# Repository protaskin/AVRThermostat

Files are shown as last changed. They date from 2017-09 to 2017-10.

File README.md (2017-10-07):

# AVRThermostat

AVRThermostat is, as the name implies, a programmable thermostat, which is built
on

* Atmel AVR ATmega8A microcontroller,

* digital thermometer DS18B20 by Maxim Integrated,

* four-digit seven-segment led display with common cathode (like CC56-12 or
FYQ-5641A),

and uses a relay to control a heater or fan. The device can be used as a simple
thermometer as well. The sensor measures temperatures from -55°C to +125°C
with ±0.5°C accuracy from -10°C to +85°C.

The thermostat has 4 buttons (Plus, Minus, Set, Reset) that are used to set up
parameters--the setpoint and the zone (delta). The longer you hold the 
Plus/Minus button, the faster a parameter increases/decreases. The Reset button
is used to set the standard value to a parameter, also to switch off the
thermostat mode. Parameters are saved in EEPROM after editing.

The Plus/Minus buttons also are used to adjust the display brightness when
the device is not in the mode of editing of a parameter.

Two leds indicate the state of the relay. If the device is not in the thermostat
mode, then both leds do not light.

If the device cannot establish connection with the sensor, the display shows
an error.

## Schematics and PCB Layout r3.x

A KiCad project, which includes a schematics and PCB layout, is located in
[the Design directory](Design/). **Please be aware that the project is made from
scratch and I have not yet used the new PCB layout myself, therefore it may have
errors.**

### Schematics

Schematics r3.1

### PCB 3D Model

PCB 3D Model r3.0

## Versioning

For transparency and insight into our release cycle, and for striving to
maintain backwards compatibility, AVRThermostat will be maintained under the
Semantic Versioning guidelines as much as possible.

For more information on SemVer, please visit http://semver.org/

## License

Copyright 2014-2017 Artyom Protaskin

Licensed under the MIT License:

http://opensource.org/licenses/MIT

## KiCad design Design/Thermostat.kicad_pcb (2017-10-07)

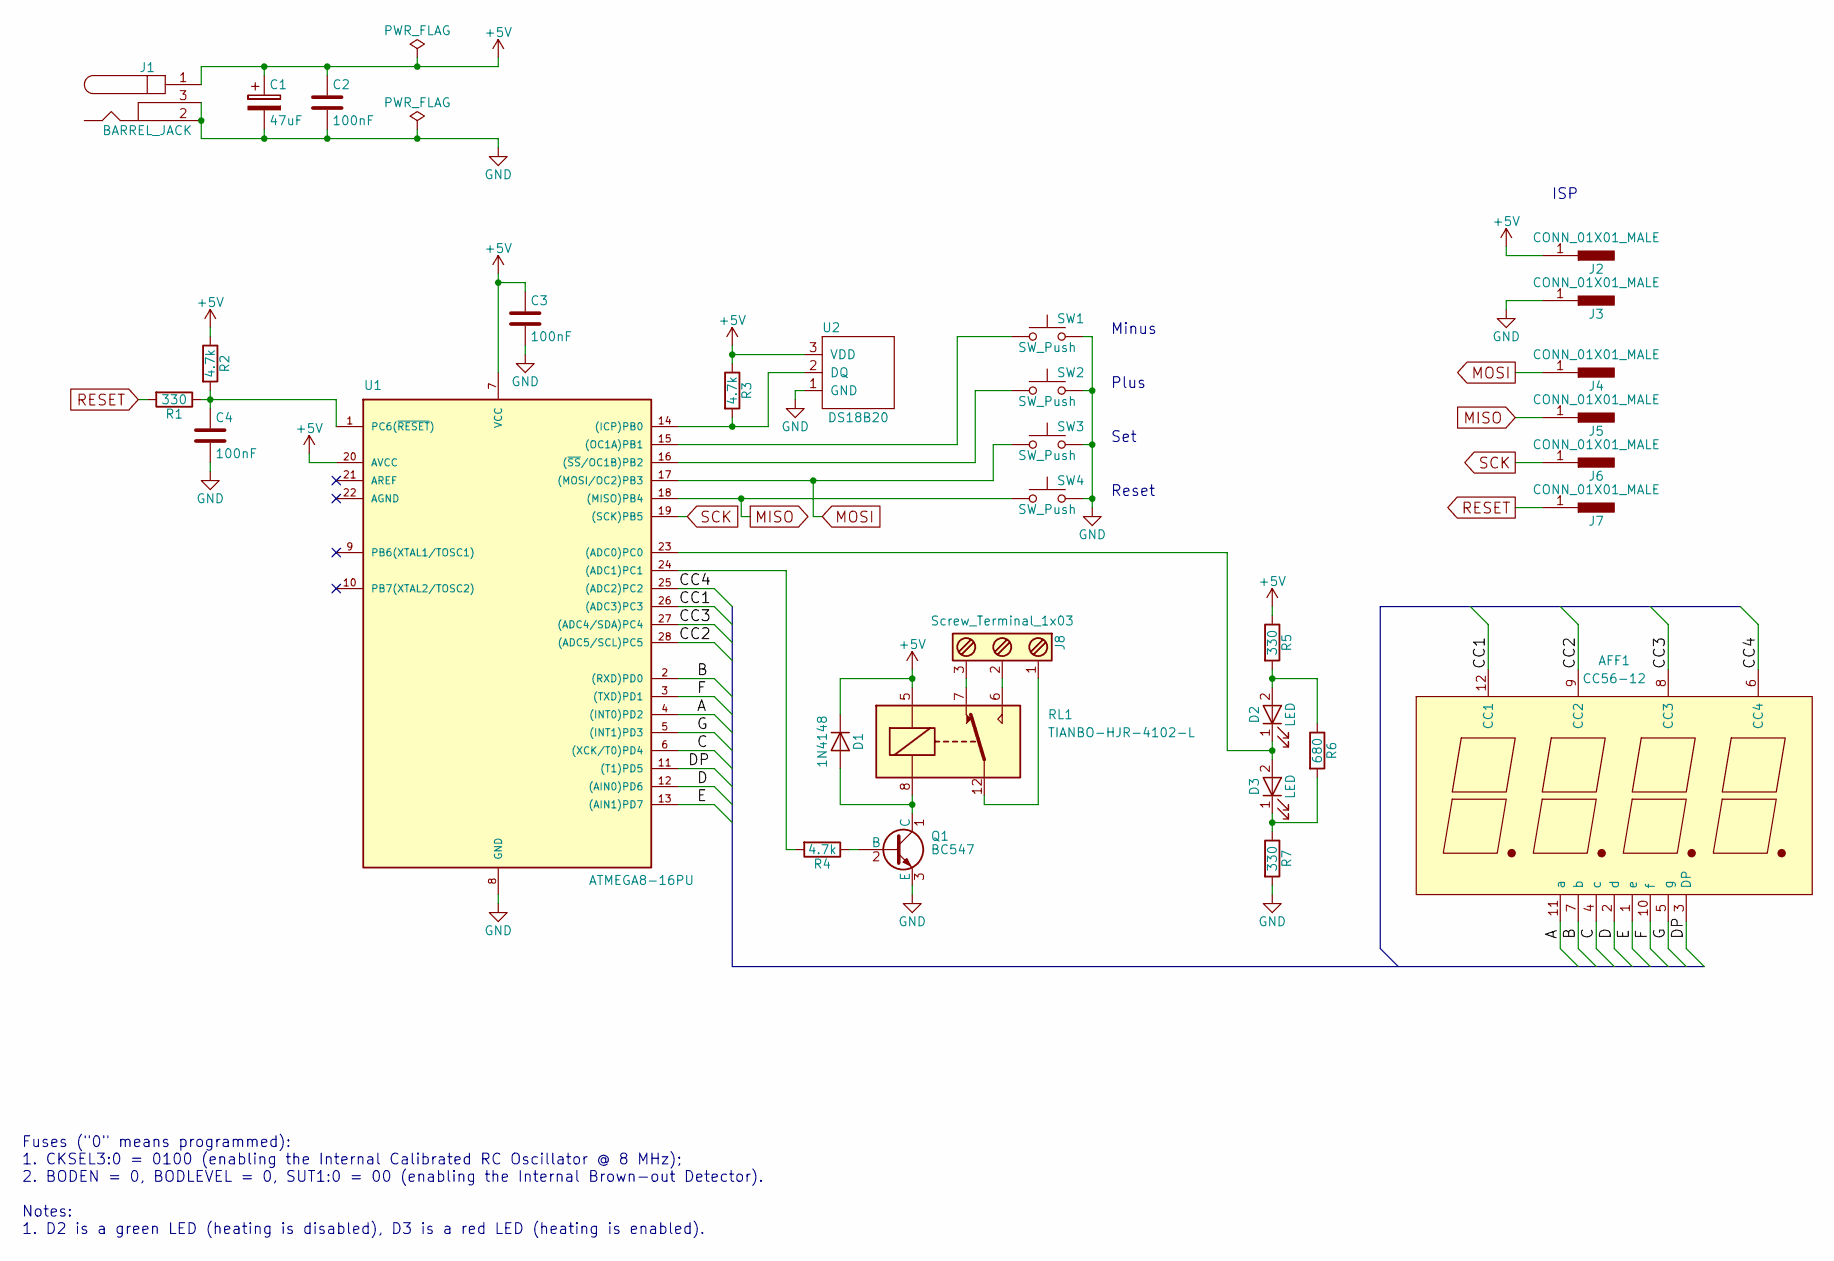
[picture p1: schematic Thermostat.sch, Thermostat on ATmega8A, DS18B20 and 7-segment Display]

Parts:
AFF1: CC56-12; CC56-12GWA
C1: 47uF; CP_Radial_D5.0mm_P2.00mm
C2, C3, C4: 100nF; C_Disc_D4.3mm_W1.9mm_P5.00mm
D1: 1N4148; D_DO-35_SOD27_P7.62mm_Horizontal
D2, D3: LED; LED_D3.0mm
J1: BARREL_JACK
J2, J3, J4, J5, J6, J7: CONN_01X01_MALE; Pin_Header_Straight_1x01_Pitch2.54mm
J8: Screw_Terminal_1x03; TerminalBlock_Pheonix_MKDS1.5-3pol
Q1: BC547; TO-92_Molded_Narrow
R1, R5, R7: 330; R_Axial_DIN0207_L6.3mm_D2.5mm_P10.16mm_Horizontal
R2, R3, R4: 4.7k; R_Axial_DIN0207_L6.3mm_D2.5mm_P10.16mm_Horizontal
R6: 680; R_Axial_DIN0207_L6.3mm_D2.5mm_P10.16mm_Horizontal
RL1: TIANBO-HJR-4102-L; Relay_SPDT_HJR-4102
SW1, SW2, SW3, SW4: SW_Push; SW_PUSH_6mm_h5mm
U1: ATMEGA8-16PU; DIP-28_W7.62mm
U2: DS18B20; TO-92_Molded_Narrow

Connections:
+5V: C1.1, C2.1, C3.1, D1.1 (K), J1.1, J2.1, R2.1, R3.1, R5.1, RL1.5, U1.7 (VCC), U1.20 (AVCC), U2.3 (VDD)
/A: AFF1.11 (a), U1.4 ((INT0)PD2)
/B: AFF1.7 (b), U1.2 ((RXD)PD0)
/C: AFF1.4 (c), U1.6 ((XCK/T0)PD4)
/CC1: AFF1.12 (CC1), U1.26 ((ADC3)PC3)
/CC2: AFF1.9 (CC2), U1.28 ((ADC5/SCL)PC5)
/CC3: AFF1.8 (CC3), U1.27 ((ADC4/SDA)PC4)
/CC4: AFF1.6 (CC4), U1.25 ((ADC2)PC2)
/D: AFF1.2 (d), U1.12 ((AIN0)PD6)
/DP: AFF1.3 (DP), U1.11 ((T1)PD5)
/E: AFF1.1 (e), U1.13 ((AIN1)PD7)
/F: AFF1.10 (f), U1.3 ((TXD)PD1)
/G: AFF1.5 (g), U1.5 ((INT1)PD3)
GND: C1.2, C2.2, C3.2, C4.2, J1.2, J1.3, J3.1, Q1.3 (E), R7.2, SW1.2, SW2.2, SW3.2, SW4.2, U1.8 (GND), U2.1 (GND)
MISO: J5.1, SW4.1, U1.18 ((MISO)PB4)
MOSI: J4.1, SW3.1, U1.17 ((MOSI/OC2)PB3)
unnamed: C4.1, R1.1, R2.2, U1.1 (PC6(~RESET~))
unnamed: D1.2 (A), Q1.1 (C), RL1.8
unnamed: D2.1 (K), D3.2 (A), U1.23 ((ADC0)PC0)
unnamed: D2.2 (A), R5.2, R6.1
unnamed: D3.1 (K), R6.2, R7.1
unnamed: J8.1, RL1.12
unnamed: J8.2, RL1.6
unnamed: J8.3, RL1.7
unnamed: Q1.2 (B), R4.1
unnamed: R3.2, U1.14 ((ICP)PB0), U2.2 (DQ)
unnamed: R4.2, U1.24 ((ADC1)PC1)
unnamed: SW1.1, U1.15 ((OC1A)PB1)
unnamed: SW2.1, U1.16 ((~SS~/OC1B)PB2)
RESET: J7.1, R1.2
SCK: J6.1, U1.19 ((SCK)PB5)

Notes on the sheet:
Minus
Plus
Set
Reset
ISP
Fuses ("0" means programmed): 1. CKSEL3:0 = 0100 (enabling the Internal Calibrated RC Oscillator @ 8 MHz); 2. BODEN = 0, BODLEVEL = 0, SUT1:0 = 00 (enabling the Internal Brown-out Detector). Notes: 1. D2 is a green LED (heating is disabled), D3 is a red LED (heating is enabled).

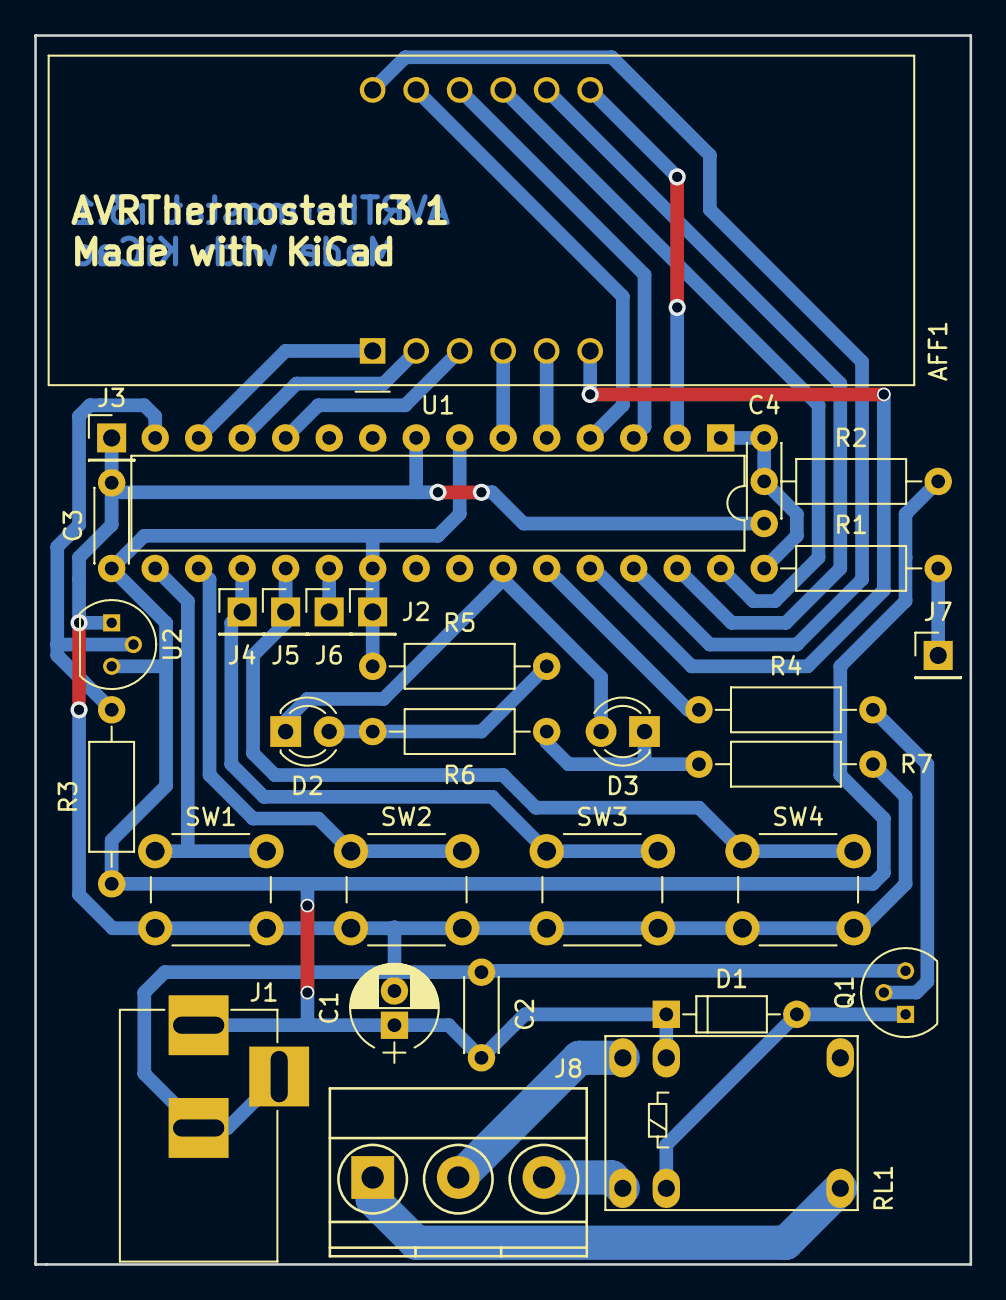
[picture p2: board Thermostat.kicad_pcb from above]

Board: 2 copper layers, 54.6 x 71.8 mm, 31 parts (0 on the bottom side), 31 nets.

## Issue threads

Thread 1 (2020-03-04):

7segment

sewer159, 2020-03-04:
Hi.
Is it possible to easily change display with a common cathode on one with common anode?

protaskin, 2020-03-05:
Not without editing/rewriting the display "driver". And hardware-wise it would probably require using transistors to switch higher output anode currents.

https://github.com/protaskin/AVRThermostat/blob/master/Thermostat/display.c
https://github.com/protaskin/AVRThermostat/blob/master/Thermostat/display.h

Closed 2020-03-06.

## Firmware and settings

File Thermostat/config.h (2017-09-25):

/*
 * This file is part of AVRThermostat.
 *
 * (c) Artyom Protaskin <a.protaskin@gmail.com>
 *
 * For the full copyright and license information, please view the LICENSE
 * file that was distributed with this source code.
 */

#ifndef CONFIG_H
#define CONFIG_H

// Limits
#define ZERO_TEMP 0
#define MIN_TEMP 0xFC90 // -55
#define MAX_TEMP 0x07D0 // 125
#define MIN_ZONE 0x0001 // 1/16
#define MAX_ZONE 0x0640 // 100
#define MIN_BRIGHTNESS 1
#define MAX_BRIGHTNESS 15

// Default values
#define DEFAULT_TASK 0x0140 // 20
#define DEFAULT_ZONE 0x0008 // 0.5
#define DEFAULT_BRIGHTNESS 7 // 1/2
#define DEFAULT_ACTION 0
#define DEFAULT_CHECKSUM 0x95

// Error bit offsets
#define CONFIG_BAD_TASK_BIT 0
#define CONFIG_BAD_ZONE_BIT 1
#define CONFIG_BAD_BRIGHTNESS_BIT 2
#define CONFIG_BAD_ACTION_BIT 3
#define CONFIG_BAD_CHECKSUM_BIT 4

#include <stdint.h>

extern uint16_t task;
extern uint16_t zone;
extern uint8_t brightness;
extern uint8_t action;

uint8_t config_read(void);

uint8_t config_update(void);

#endif /* CONFIG_H */

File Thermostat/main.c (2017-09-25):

/*
 * This file is part of AVRThermostat.
 *
 * (c) Artyom Protaskin <a.protaskin@gmail.com>
 *
 * For the full copyright and license information, please view the LICENSE
 * file that was distributed with this source code.
 */

#define TIMER1_SHOW_TEMP_BIT    0
#define TIMER1_CONTROL_TEMP_BIT 1

#include <stdbool.h>
#include <stdint.h>
#include <util/delay.h>
#include <avr/interrupt.h>
#include <avr/io.h>

#include "buttons.h"
#include "display.h"
#include "config.h"
#include "ds18b20.h"
#include "iodef.h"

static uint8_t timer1_status;
static volatile uint16_t temp = 0xDEAD;

static const uint8_t * const numbers = display_numbers_map;

/**
 * Разбивает значение, считанное из температурного регистра на рязряды и
 * заполняет регистр дисплея.
 */
static void fill_display_register(uint16_t temp)
{
	bool sign;
	uint8_t int_part, frac_numer;

	if (temp == DS18B20_ERROR) {
		display_register[3] = DISPLAY_CHAR_BLANK;
		display_register[2] = DISPLAY_CHAR_E;
		display_register[1] = DISPLAY_CHAR_R;
		display_register[0] = DISPLAY_CHAR_R;
		return;
	}

	// Определение знака
	sign = ((temp & 0xF800) == 0xF800);
	if (sign) {
		// Преобразование из дополнительного представления числа в прямое
		temp = ~temp + 1;
	}

	// Выделение целой части
	int_part = (temp & 0x07F0) >> 4;

	// Выделение дробной части
	frac_numer = (temp & 0x0F) * 625 / 100;
	frac_numer = frac_numer / 10 + (frac_numer % 10 >= 5);

	// Заполнение регистра дисплея
	if (int_part >= 100) {
		display_register[3] = numbers[1];
	} else if (sign && int_part >= 10) {
		display_register[3] = DISPLAY_CHAR_MINUS;
	} else {
		display_register[3] = DISPLAY_CHAR_BLANK;
	}

	if (int_part >= 10) {
		display_register[2] = numbers[int_part % 100 / 10];
	} else if (sign) {
		display_register[2] = DISPLAY_CHAR_MINUS;
	} else {
		display_register[2] = DISPLAY_CHAR_BLANK;
	}

	display_register[1] = numbers[int_part % 10] | DISPLAY_CHAR_POINT;
	display_register[0] = numbers[frac_numer];
}

/**
 * Считывает содержимое температурного регистра. Вызывается 1 раз в 2 с.
 */
ISR(TIMER1_COMPA_vect)
{
	uint16_t trigger_on;
	uint16_t trigger_off;

	temp = ds18b20_read_temp();

	if (timer1_status & _BV(TIMER1_SHOW_TEMP_BIT)) {
		fill_display_register(temp);
	}

	if (timer1_status & _BV(TIMER1_CONTROL_TEMP_BIT)) {
		trigger_on = task - zone / 2;
		trigger_off = task + zone / 2;

		// If temp >= MIN_TEMP is true, temp is negative,
		// If temp <= MAX_TEMP is true, temp is positive.
		if (temp >= MIN_TEMP) {
			if (trigger_on <= MAX_TEMP || temp <= trigger_on) {
				LED_PORT |= _BV(LED_BIT);
				RELAY_PORT |= _BV(RELAY_BIT);
			} else if (trigger_off >= MIN_TEMP && temp >= trigger_off) {
				LED_PORT &= ~_BV(LED_BIT);
				RELAY_PORT &= ~_BV(RELAY_BIT);
			}
		} else {
			if (trigger_on <= MAX_TEMP && temp <= trigger_on) {
				LED_PORT |= _BV(LED_BIT);
				RELAY_PORT |= _BV(RELAY_BIT);
			} else if (trigger_off >= MIN_TEMP || temp >= trigger_off) {
				LED_PORT &= ~_BV(LED_BIT);
				RELAY_PORT &= ~_BV(RELAY_BIT);
			}
		}
	}
}

/**
 * Отображает содержимое регистра дисплея. Вызывается 1 раз в 100 мкс.
 */
ISR(TIMER2_COMP_vect)
{
	static uint8_t i = 0;

	if (i == 0) {
		display_show();
	}

	if (i == brightness) {
		display_hide();
		display_next();
	}

	i++;
	i &= 0x0F; // 16 -> 0
}

static void show_temp()
{
	timer1_status |= _BV(TIMER1_SHOW_TEMP_BIT);
	fill_display_register(temp);

	for (;;) {
		if (button_is_pressed(&BUTTONS_PIN, MINUS_BUTTON_BIT)) {
			if (brightness > MIN_BRIGHTNESS) {
				brightness--;
				config_update();
			}
			while (!button_is_released(&BUTTONS_PIN, MINUS_BUTTON_BIT));
		} else if (button_is_pressed(&BUTTONS_PIN, PLUS_BUTTON_BIT)) {
			if (brightness < MAX_BRIGHTNESS) {
				brightness++;
				config_update();
			}
			while (!button_is_released(&BUTTONS_PIN, PLUS_BUTTON_BIT));
		} else if (button_is_pressed(&BUTTONS_PIN, SET_BUTTON_BIT)) {
			while (!button_is_released(&BUTTONS_PIN, SET_BUTTON_BIT));
			break;
		}
	}

	timer1_status &= ~_BV(TIMER1_SHOW_TEMP_BIT);
}

static void change_task()
{
	bool reset;

	fill_display_register(task);

	for (;;) {
		reset = true;
		if (button_is_pressed(&BUTTONS_PIN, MINUS_BUTTON_BIT)) {
			do {
				if (task <= MAX_TEMP || task > MIN_TEMP) {
					fill_display_register(--task);
				}
			} while (button_being_pressed(&BUTTONS_PIN, MINUS_BUTTON_BIT, &reset));
		} else if (button_is_pressed(&BUTTONS_PIN, PLUS_BUTTON_BIT)) {
			do {
				if (task < MAX_TEMP || task >= MIN_TEMP) {
					fill_display_register(++task);
				}
			} while (button_being_pressed(&BUTTONS_PIN, PLUS_BUTTON_BIT, &reset));
		} else if (button_is_pressed(&BUTTONS_PIN, SET_BUTTON_BIT)) {
			while (!button_is_released(&BUTTONS_PIN, SET_BUTTON_BIT));
			return;
		} else if (button_is_pressed(&BUTTONS_PIN, RESET_BUTTON_BIT)) {
			task = DEFAULT_TASK;
			fill_display_register(task);
			while (!button_is_released(&BUTTONS_PIN, RESET_BUTTON_BIT));
		}
	}
}

static void change_zone()
{
	bool reset;

	fill_display_register(zone);

	for (;;) {
		reset = true;
		if (button_is_pressed(&BUTTONS_PIN, MINUS_BUTTON_BIT)) {
			do {
				if (zone > MIN_ZONE) {
					fill_display_register(--zone);
				}
			} while (button_being_pressed(&BUTTONS_PIN, MINUS_BUTTON_BIT, &reset));
		} else if (button_is_pressed(&BUTTONS_PIN, PLUS_BUTTON_BIT)) {
			do {
				if (zone < MAX_ZONE) {
					fill_display_register(++zone);
				}
			} while (button_being_pressed(&BUTTONS_PIN, PLUS_BUTTON_BIT, &reset));
		} else if (button_is_pressed(&BUTTONS_PIN, SET_BUTTON_BIT)) {
			while (!button_is_released(&BUTTONS_PIN, SET_BUTTON_BIT));
			return;
		} else if (button_is_pressed(&BUTTONS_PIN, RESET_BUTTON_BIT)) {
			zone = DEFAULT_ZONE;
			fill_display_register(zone);
			while (!button_is_released(&BUTTONS_PIN, RESET_BUTTON_BIT));
		}
	}
}

static void control_temp()
{
	timer1_status |= _BV(TIMER1_SHOW_TEMP_BIT) | _BV(TIMER1_CONTROL_TEMP_BIT);
	fill_display_register(temp);

	LED_DDR |= _BV(LED_BIT);
	LED_PORT &= ~_BV(LED_BIT); // Включение индикации

	for (;;) {
		if (button_is_pressed(&BUTTONS_PIN, MINUS_BUTTON_BIT)) {
			if (brightness > MIN_BRIGHTNESS) {
				brightness--;
				config_update();
			}
			while (!button_is_released(&BUTTONS_PIN, MINUS_BUTTON_BIT));
		} else if (button_is_pressed(&BUTTONS_PIN, PLUS_BUTTON_BIT)) {
			if (brightness < MAX_BRIGHTNESS) {
				brightness++;
				config_update();
			}
			while (!button_is_released(&BUTTONS_PIN, PLUS_BUTTON_BIT));
		} else if (button_is_pressed(&BUTTONS_PIN, RESET_BUTTON_BIT)) {
			LED_DDR &= ~_BV(LED_BIT);
			LED_PORT &= ~_BV(LED_BIT);
			RELAY_PORT &= ~_BV(RELAY_BIT); // Выключение индикации и управления
			while (!button_is_released(&BUTTONS_PIN, RESET_BUTTON_BIT));
			break;
		}
	}

	timer1_status &= ~(_BV(TIMER1_SHOW_TEMP_BIT) | _BV(TIMER1_CONTROL_TEMP_BIT));
}

int main()
{
	uint8_t error;

	// Enable internal pull-up resistors
	BUTTONS_PORT |= _BV(MINUS_BUTTON_BIT) | _BV(PLUS_BUTTON_BIT) |
		_BV(SET_BUTTON_BIT) | _BV(RESET_BUTTON_BIT);

	// Конфигурация портов в/в
	RELAY_DDR = _BV(RELAY_BIT);

	// Конфигурация 16-битного счетчика
	OCR1AH = 0x3D;
	OCR1AL = 0x08; // Счет до 15625
	// WGM12 = 1 для сброса при совпадении (режим CTC)
	// CS12 = 1 и CS10 = 1 для предварительного деления на 1024
	TCCR1B = _BV(WGM12) | _BV(CS12) | _BV(CS10);
	TIMSK |= _BV(OCIE1A); // Включение прерывания по совпадению

	// Конфигурация 8-битного счетчика
	OCR2 = 0x18; // Счет до 25
	// WGM21 = 1 для сброса при совпадении (режим CTC)
	// CS21 = 1 и CS20 = 1 для предварительного деления на 32
	TCCR2 = _BV(WGM21) | _BV(CS21) | _BV(CS20);
	TIMSK |= _BV(OCIE2); // Включение прерывания по совпадению

	// Инициализация дисплея
	display_init();

	sei();

	error = config_read();
	if (error) {
		if (error & _BV(CONFIG_BAD_CHECKSUM_BIT)) {
			display_register[3] = DISPLAY_CHAR_BLANK;
			display_register[2] = DISPLAY_CHAR_C;
			display_register[1] = DISPLAY_CHAR_R;
			display_register[0] = DISPLAY_CHAR_C;
		}

		while (!button_is_pressed(&BUTTONS_PIN, RESET_BUTTON_BIT));
		while (!button_is_released(&BUTTONS_PIN, RESET_BUTTON_BIT));
	}

	// Skip the power-on reset value of the temperature
	ds18b20_read_temp();
	while (temp == 0xDEAD) {
		display_register[3] = DISPLAY_CHAR_L;
		display_register[2] = DISPLAY_CHAR_O;
		display_register[1] = DISPLAY_CHAR_A;
		display_register[0] = DISPLAY_CHAR_D;
	}

	while (true) {
		switch (action) {
			case 0:
				config_update();
				show_temp();
				break;
			case 1:
				change_task();
				break;
			case 2:
				change_zone();
				break;
			case 3:
				config_update();
				control_temp();
				break;
		}

		action++;
	}
}

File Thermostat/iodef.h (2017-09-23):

/*
 * This file is part of AVRThermostat.
 *
 * (c) Artyom Protaskin <a.protaskin@gmail.com>
 *
 * For the full copyright and license information, please view the LICENSE
 * file that was distributed with this source code.
 */

#ifndef IODEF_H
#define IODEF_H

// Buttons
#define BUTTONS_DDR      DDRB
#define BUTTONS_PORT     PORTB
#define BUTTONS_PIN      PINB
#define MINUS_BUTTON_BIT PB1
#define PLUS_BUTTON_BIT  PB2
#define SET_BUTTON_BIT   PB3
#define RESET_BUTTON_BIT PB4

// LED
#define LED_DDR  DDRC
#define LED_PORT PORTC
#define LED_PIN  PINC
#define LED_BIT  PC0

// Relay
#define RELAY_DDR  DDRC
#define RELAY_PORT PORTC
#define RELAY_PIN  PINC
#define RELAY_BIT  PC1


// Display digits
#define DISPLAY_DIGITS_DDR  DDRC
#define DISPLAY_DIGITS_PORT PORTC
#define DISPLAY_DIGITS_PIN  PINC

#define DISPLAY_1_BIT PC3
#define DISPLAY_2_BIT PC5
#define DISPLAY_3_BIT PC4
#define DISPLAY_4_BIT PC2

// Display segments
#define DISPLAY_SEGMENTS_DDR  DDRD
#define DISPLAY_SEGMENTS_PORT PORTD
#define DISPLAY_SEGMENTS_PIN  PIND

#define DISPLAY_A_BIT  PD2
#define DISPLAY_B_BIT  PD0
#define DISPLAY_C_BIT  PD4
#define DISPLAY_D_BIT  PD6
#define DISPLAY_E_BIT  PD7
#define DISPLAY_F_BIT  PD1
#define DISPLAY_G_BIT  PD3
#define DISPLAY_DP_BIT PD5

// DS18B20
#define DS18B20_DDR  DDRB
#define DS18B20_PORT PORTB
#define DS18B20_PIN  PINB
#define DS18B20_BIT  PB0

#endif /* IODEF_H */

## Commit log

2016-11-09 Fix possible reactivation of the leds and relay
    Fix possible reactivation of the leds and relay during switching off
    the thermostat mode by the TIMER1_COMPA_vect interrupt (or by holding
    the reset button pressed (ab3618b regression)).
    [main.c]
2017-01-03 Update the location of the schematics file
2017-01-03 Update the schematics, add the link to the PCB layout in Gerber
2017-07-30 Add a design project remade with KiCad
    The new design also includes the following minor changes:
    - Added decoupling capacitors
    - Added "the reset circuit"
    - Connected AVCC to VCC
    - Removed the ISP IDC, added pin headers instead
    - Swapped PC4 and PC5 outputs
    [Thermostat.kicad_pcb, Thermostat.sch]
2017-09-23 Refactor the project's macros
    - Replaced the display I/O configuration mask macros with bit offset macros
    - Moved all the I/O configuration macros to iodef.h
    - Renamed DISPLAY_DIGITS_COUNT to DISPLAY_REGISTER_SIZE
    [iodef.h, main.c]
2017-09-25 Refactor timer1 status byte
2017-09-25 Refactor skipping the power-on reset value of the temperature
    [main.c]
2017-09-25 Update the EEPROM-specific code
    - Moved the EEPROM-specific code to the config module
    - Added function to calculate the checksum of the parameters stored
    in EEPROM (uses the standard avr-gcc _crc_ibutton_update function)
    - Added functions to read and update the parameters stored in EEPROM,
    which also check the checksum and keep it updated
    - Added showing an error message in case of reading an incorrect value
    of any parameter (only the power-on reading yet)
    [config.h, main.c]
2017-10-07 Add a recommendation to enabling the BOD
    [Thermostat.kicad_pcb, Thermostat.sch]
